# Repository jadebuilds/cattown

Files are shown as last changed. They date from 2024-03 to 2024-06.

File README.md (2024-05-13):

# cattown
Code for Cat Town Kickstarter project

# Poetry Environment Setup Instructions
-Make sure Python 3.12.3 exists on the system

-Install Poetry:

curl -sSL https://install.python-poetry.org/ | python3 -

May have to add this to path to run Poetry: `export PATH="/home/<YOUR USERNAME>/.local/bin:$PATH"`

The Poetry lock file and pyproject.toml should all be pulled from git.

You can now cd into `cattown/pi-controller` and run `poetry install` to make sure dependencies are installed.

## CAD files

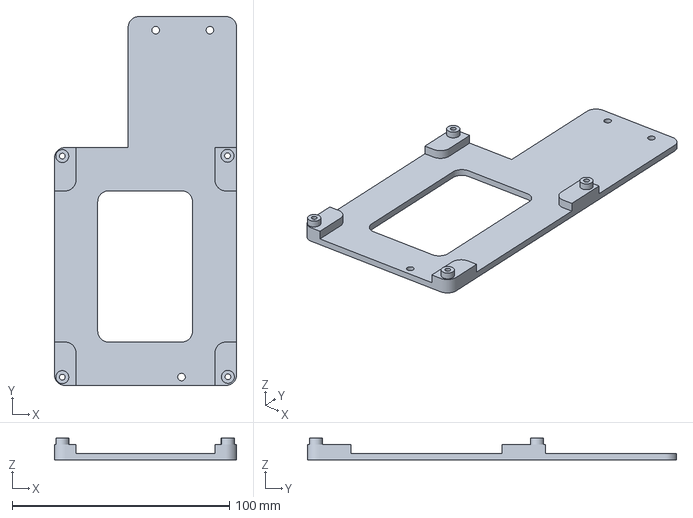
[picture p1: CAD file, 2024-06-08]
3d Print files/electronics/Powersupply main board mount.3MF
84.0 x 170.0 x 10.0 mm

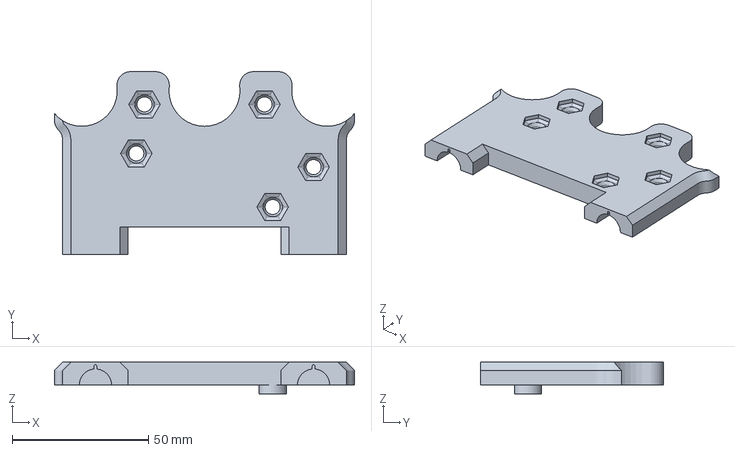
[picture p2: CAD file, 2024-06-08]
3d Print files/Gantry mount/top back gantry mount V0.02.3MF
110.0 x 67.0 x 11.6 mm

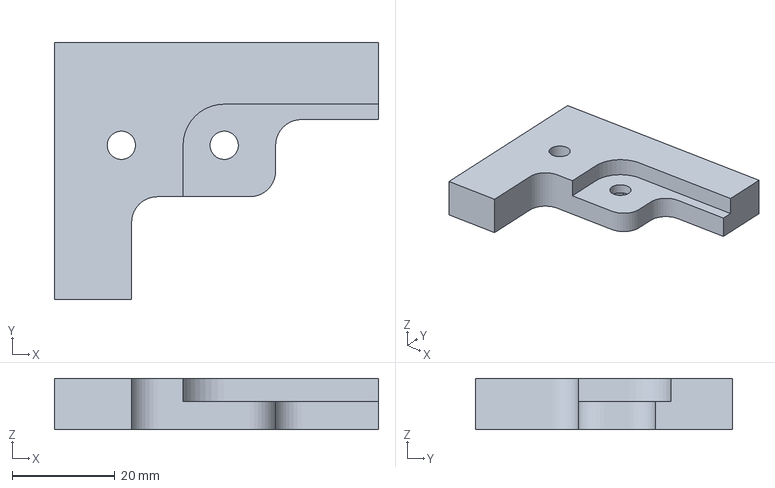
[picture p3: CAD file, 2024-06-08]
3d Print files/Idler mount/Top back idler mount.3MF
63.0 x 50.0 x 10.0 mm

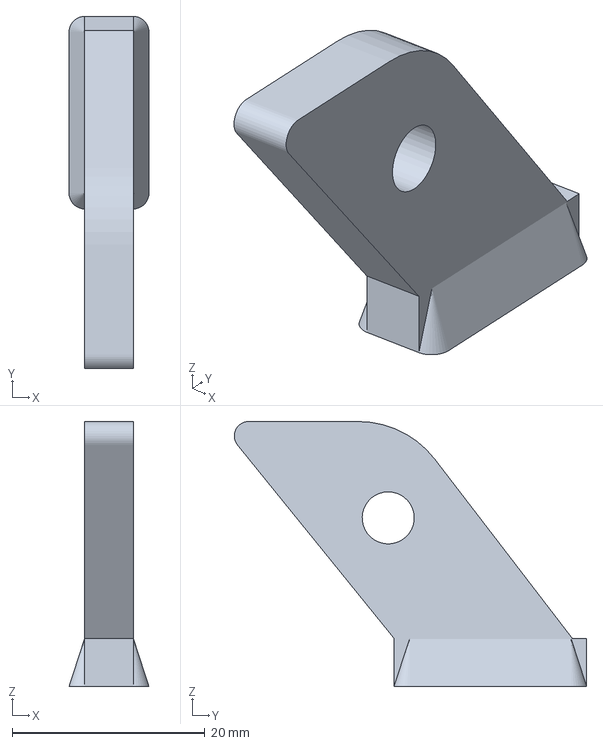
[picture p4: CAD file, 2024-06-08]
3d Print files/Jointer/v5_play_structure_v3_v25_joiner (1).3MF
8.30 x 36.6 x 27.5 mm

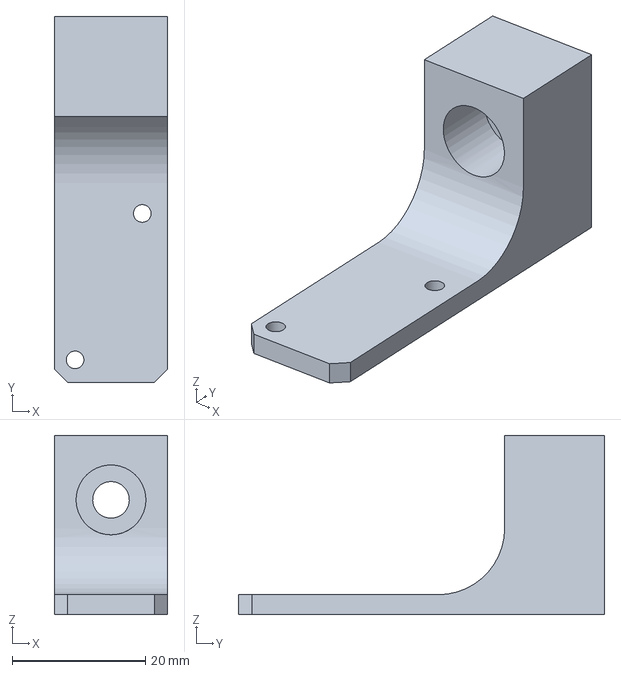
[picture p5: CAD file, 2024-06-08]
3d Print files/Limit switch mount/Limit switch mount v0.21.3MF
17.0 x 55.0 x 27.0 mm

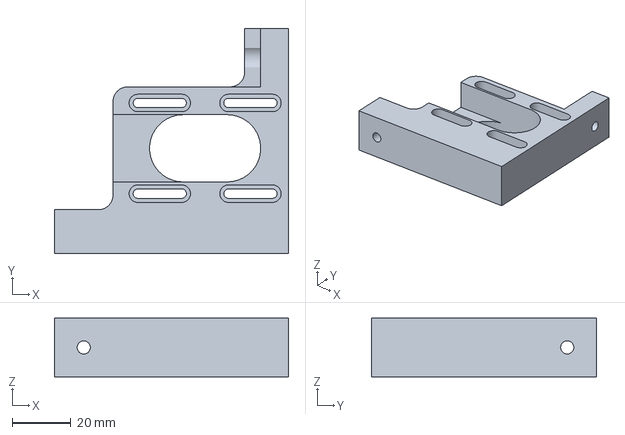
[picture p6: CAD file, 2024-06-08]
3d Print files/Motor mounts/Bottom motor mount.3MF
80.0 x 77.0 x 20.0 mm

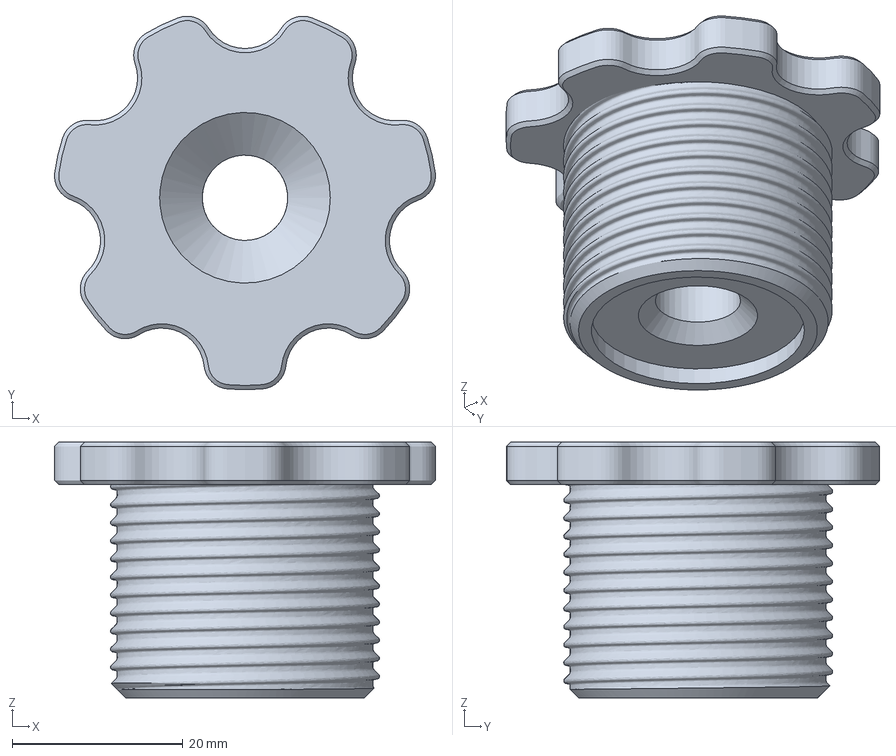
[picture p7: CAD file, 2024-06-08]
3d Print files/Tool head/Magnet holder.3MF
44.7 x 43.8 x 30.0 mm

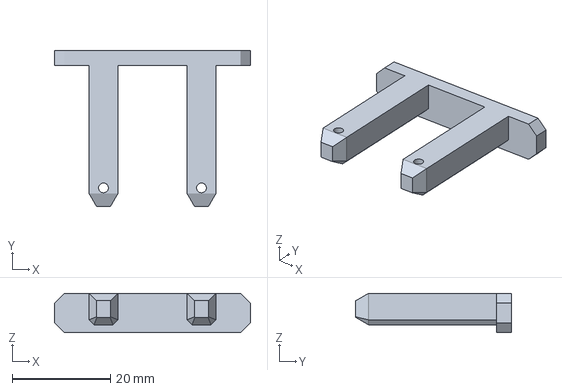
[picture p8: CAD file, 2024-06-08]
3d Print files/Tools/2040 frame mount hole guild.3MF
40.0 x 31.8 x 8.00 mm

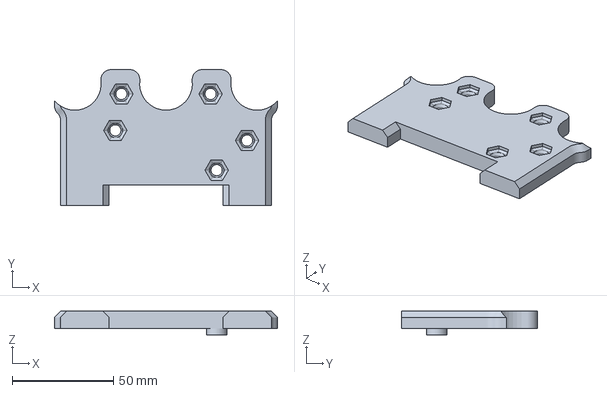
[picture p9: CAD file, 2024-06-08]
3d Print files/Gantry mount/top back gantry mount.3MF
110.0 x 67.0 x 11.6 mm

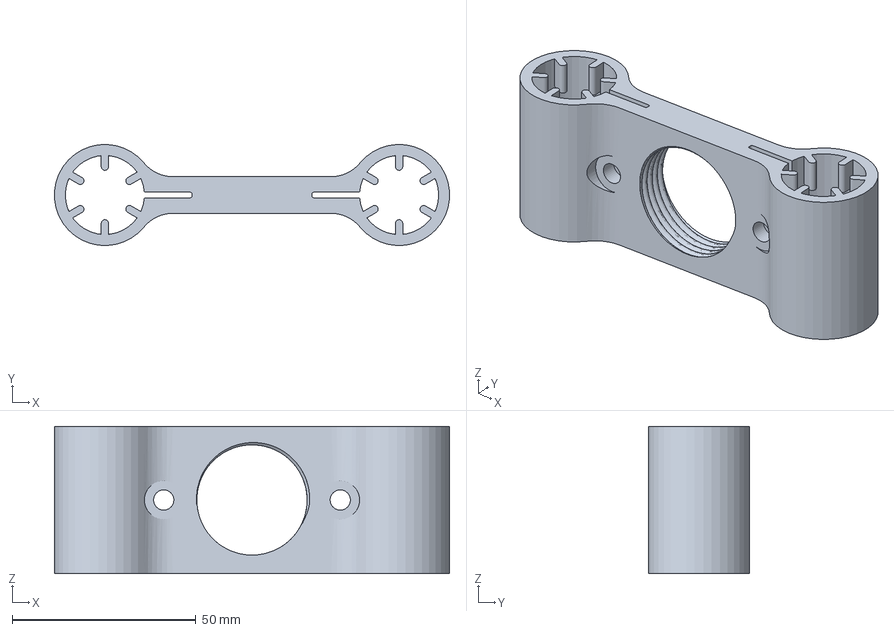
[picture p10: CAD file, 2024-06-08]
3d Print files/Tool head/Tool head.3MF
107.4 x 27.5 x 40.0 mm

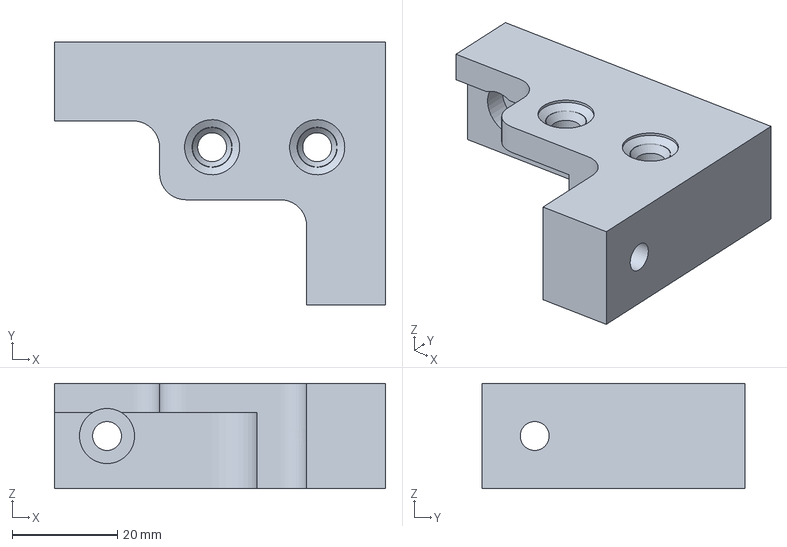
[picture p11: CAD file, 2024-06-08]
3d Print files/Idler mount/Bottom front idler mount.3MF
63.0 x 50.0 x 20.0 mm

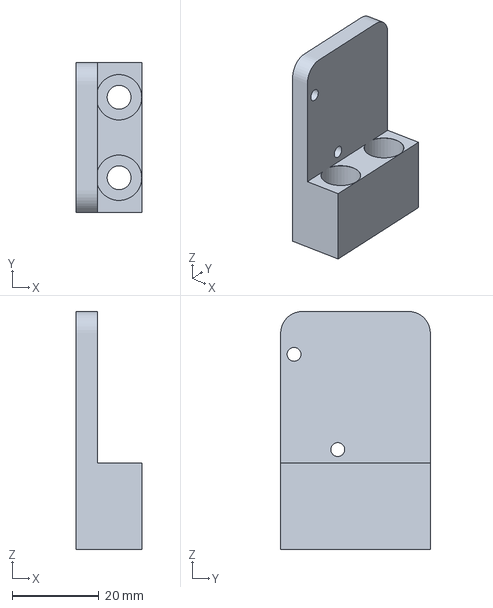
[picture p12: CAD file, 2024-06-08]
3d Print files/Limit switch mount/Limit switch mount.3MF
15.3 x 34.6 x 55.0 mm

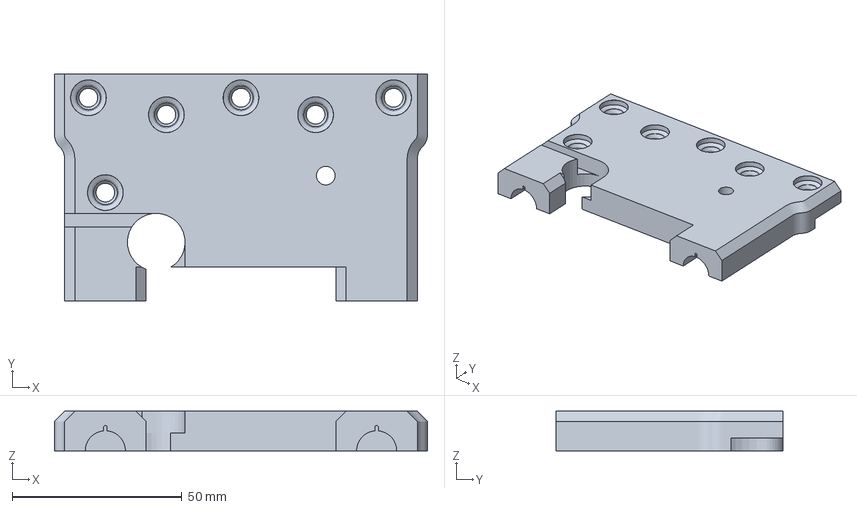
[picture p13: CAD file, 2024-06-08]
3d Print files/Gantry mount/top front gantry mount.3MF
110.0 x 67.0 x 11.7 mm

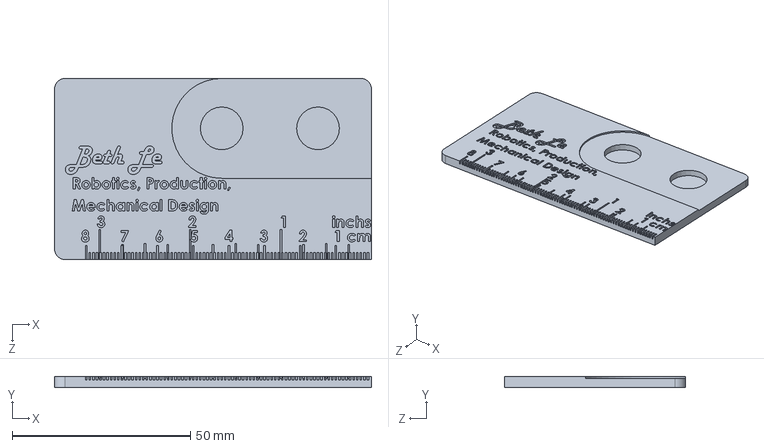
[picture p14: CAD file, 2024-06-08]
3d Print files/Tool head/Card.SLDPRT
88.9 x 3.00 x 50.8 mm

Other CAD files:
3d Print files/Idler mount/Bottom back idler mount.3MF
3d Print files/Motor mounts/Top motor mount.3MF
3d Print files/Gantry mount/Bottom back gantry mount.3MF
3d Print files/Idler mount/Top front idler mount v0.02.3MF
3d Print files/Gantry mount/Bottom front gantry mount.3MF
3d Print files/Gantry mount/top front gantry mount v0.02.3MF
3d Print files/Idler mount/Top front idler mount.3MF
3d Print files/Limit switch mount/Limit switch mount v0.20.3MF
3d Print files/Tool head/Belt holder v0.02.3MF
3d Print files/Tool head/Belt holder.3MF
3d Print files/Tool head/Bushing v0.02.3MF
3d Print files/Tool head/Bushing v0.03.3MF
3d Print files/Tool head/Bushing v0.04.3MF
3d Print files/Tool head/Bushing v0.05.3MF
3d Print files/Tool head/Bushing v0.06.3MF
3d Print files/Tool head/Bushing v0.07.3MF
3d Print files/Tool head/Bushing.3MF
3d Print files/Tool head/Magnet holder v0.02.3MF
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

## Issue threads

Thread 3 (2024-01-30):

Stabilizing strategy for the carriage

jadebuilds, 2024-01-30:
Decide on whether/how we're going to stabilize the carriage. Counterweights? Bungees? How will we access the lower corners of the platform? Or can we simply get away without it?

Requires some mechanical testing and prototyping.

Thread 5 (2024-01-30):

Jungle gym frontend

jadebuilds, 2024-01-30:
Design and lasercut some mouse houses, ramps/platforms, maybe some cat beds. Assemble onto the plywood sheet (presumably with wood glue?).

Decisions to make along the way:

* Size / orientation / number of mouse houses
* Freestanding or supported by the sheet?
* "What's fun for a cat?"
* Portrait/landscape orientation ("locks us in" -- although nb. we could make two gyms if we wanted to compare/contrast)

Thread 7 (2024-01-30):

Wire harnesses

jadebuilds, 2024-01-30:
Make a harness or harnesses to carry armature power to the motors.

The harness should ideally be connectorized to the electronics box such that the box can be detached for transport.

Leave conductors (or at least pins!) for 2x thermistors and 2x limit switches.

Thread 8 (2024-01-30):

Firmware: X/Y control

jadebuilds, 2024-01-30:
Write firmware to support play testing that:

* Includes some means of calibration -- probably as simple as a "disable motor drive" switch so we can manually spin the pulleys to a known starting position
* Allows X/Y control with the joystick
* Supports switching between direct motor drive (up/down = motor 1 extend/retract) and X/Y drive (up/down = up/down)

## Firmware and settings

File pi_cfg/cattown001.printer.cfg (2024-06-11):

# CAT TOWN V5
#
# This file is based off of the example Klipper config here:
# https://github.com/Klipper3d/klipper/blob/master/config/generic-bigtreetech-skr-v1.4.cfg
#
# Any line that isn't commented should be assumed to come from that.
#
# Pinout is here:
# https://raw.githubusercontent.com/bigtreetech/BIGTREETECH-SKR-V1.3/master/BTT%20SKR%20V1.4/Hardware/SKR-V1.4-Turbo-pinout.jpg
[mcu]
serial: /dev/serial/by-id/usb-Klipper_lpc1768_226002056324E6956623A363862100F5-if00

[include mainsail.cfg]  # this is just to make Mainsail happy. Does it matter for us?? idk

[duplicate_pin_override]
pins: P1.27

[printer]
kinematics: corexy
max_velocity: 10000
max_accel: 10000
max_z_velocity: 10
max_z_accel: 100

[stepper_x]
step_pin: P2.2
dir_pin: P2.6
enable_pin: !P2.1
microsteps: 16
rotation_distance: 60
# SKR1.4 uses the same P1.29/P1.28 pins for the X and Y endstops and Diag from the TMC2209s;
# I'm going to use the Z endstop pin for the actual endstop switch and leave the diag pins
# active for StallGuard detection. Hopefully that works! 
endstop_pin: !P1.27  # Z-stop pin (because X and Y-stop pins are overridden with diag) 
# endstop_pin:tmc2209_stepper_x:virtual_endstop
position_min:0
position_endstop:0
position_max: 1450  # approximately 57" X travel -- needs dialing in
homing_speed: 100
homing_retract_dist: 50

[stepper_y]
step_pin: P0.19
dir_pin: !P0.20
enable_pin: !P2.8
microsteps: 16
rotation_distance: 60
endstop_pin: !P1.27  # Beth's magical girl arc involves using the same endstop for both X and Y
# (which, as above, will actually be on this board's Z-stop connector)
# endstop_pin:tmc2209_stepper_y:virtual_endstop
position_min: 0
position_endstop: 0
position_max: 915  # leaving a few millimeters of tolerance at the upper end
homing_speed: 100

[stepper_z]
step_pin: P0.22
dir_pin: !P2.11
enable_pin: !P0.21
microsteps: 16
rotation_distance: 8
endstop_pin: !P1.27
position_endstop: 0.0
position_max: 300

[extruder]
step_pin: P2.13
dir_pin: !P0.11
enable_pin: !P2.12
microsteps: 16
rotation_distance: 33.500
nozzle_diameter: 0.400
filament_diameter: 1.750
heater_pin: P2.7
sensor_type: EPCOS 100K B57560G104F
sensor_pin: P0.24
control: pid
pid_Kp: 22.2
pid_Ki: 1.08
pid_Kd: 114
min_temp: -273.15
max_temp: 1000000

[fan]
pin: P2.3






########################################
# TMC2209 configuration
########################################

# see klipper3d.org/TMC_Drivers.html

[tmc2209 stepper_x]
uart_pin: P1.10
diag_pin: P1.29
run_current: 1.800
stealthchop_threshold: 0  # stealthChop all day (for quiet)
driver_SGTHRS: 255  # most sensitive (to try out)
diag_pin: ^P1.29
interpolate: True  # may reduce audible noise in exchange for minor positional inaccuracy
# Setting a hold current isn't recommended by the Klipper docs, but for our 
# application it makes a lot of sense: we do a lot of holding, we don't want to 
# run too hot, and also our carriage is super light and doesn't require much
# holding force. So I'm definitely trying this one out.
hold_current: 0.25

[tmc2209 stepper_y]
uart_pin: P1.9
diag_pin: P1.28
run_current: 1.8
stealthchop_threshold: 0
driver_SGTHRS: 255
diag_pin: ^P1.28
interpolate: True
hold_current: 0.25

#####################################################################
# 	Homing and Gantry Adjustment Routines
#####################################################################

[idle_timeout]
timeout: 1800


########################################
# G-code macros
########################################

[gcode_arcs]
resolution: 1.0

[homing_override]
gcode:
    #G91  # set to relative movement
    #G1 Y10  # move the carriage down by 10mm so that its homing tab is away from the limit switch
    #G92  # back to absolute
    G28 X0  # home on X axis first
    G1 X10  # move the gantry out to the right enough for the homing tab to contact the limit switch
    G28 Y0  # home on Y axis next (will bring the carriage up until it contacts the limit switch











########################################
# EXP1 / EXP2 (display) pins
########################################

# We don't need this right???? this is from the example .cfg

#[board_pins]
#aliases:
#    # EXP1 header
#    EXP1_1=P1.30, EXP1_3=P1.18, EXP1_5=P1.20, EXP1_7=P1.22, EXP1_9=<GND>,
#    EXP1_2=P0.28, EXP1_4=P1.19, EXP1_6=P1.21, EXP1_8=P1.23, EXP1_10=<5V>,
#    # EXP2 header
#    EXP2_1=P0.17, EXP2_3=P3.26, EXP2_5=P3.25, EXP2_7=P1.31, EXP2_9=<GND>,
#    EXP2_2=P0.15, EXP2_4=P0.16, EXP2_6=P0.18, EXP2_8=<RST>, EXP2_10=<NC>
#    # Pins EXP2_1, EXP2_6, EXP2_2 are also MISO, MOSI, SCK of bus "ssp0"

# See the sample-lcd.cfg file for definitions of common LCD displays.

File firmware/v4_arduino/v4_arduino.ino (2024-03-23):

#include <LiquidCrystal.h>
#include <TMCStepper.h>
#include "kinematics.h"
#include "pwm.h"
#include <arduino-timer.h>


/*
 * This is a first pass at making V4 work. I'm going just for "Manual Mode" right now;
 * accepting commands is for later.
 * 
 * I'm writing for E-S Motor 4260BL motors, assuming a Maslow-style design with a cable
 * pull doing stabilization.
 * 
 */

// ~~~~~~~~~~~~~~~~~~~~~~~~~~~~~~~~ CONSTANTS ~~~~~~~~~~~~~~~~~~~~~~~~~~~~~~~~

// todo should these be #defines?
const int DEBUG_UART_BAUD = 115200;

// I'm going fairly slowly for the moment because I expect to introduce discontinuities
// into the PWM output each time we change the PWM duty cycle (I keep disabling and re-enabling
// those channels)
const int MAIN_LOOP_PERIOD_MILLIS = 100;  // used in a delay() call in each loop()

const int PULLEY_DIAMETER_UM = 20000;  // 20 mm diameter pulley
const int PULLEY_PERIMETER_UM = 62832;  // 20 mm * pi

// How fast should a mouse accelerate? For my first pass I'll try 1G (9/8 m/s^2).
// With a 25 mm pulley diameter that works out to 
// dw/dt = a/r = (9.8 m/s^2) / (0.0125 m) * (60 s / 1 min) * (1 rev / 2π) = 7480 rpm/s
// So basically I'll allow the motor to ramp up to full over one second.
// Actually thinking about it I'm gonna use the Nice Round Number of 8000 rpm/s,
// which should work out to 1.07 G (very close) and invites a world of pleasant integral
// calculations. Also constitutes the motor spinning up fully over half a second which is
// nicne and round to think about.

// Note that I might move away from RPM as a measure of rotational speed but for now
// it seems both nicely legible and large enough to be pleasantly integral. So we're gonna
// stick with it for the moment and see how it feels.
//const int MAX_ACCEL_RPM_PER_S = 8000;

// Actually I want to accelerate much slower than that for testing. Let's do this (todo remove me)
const int MAX_ACCEL_RPM_PER_S = 200;

// In testing I'm finding that I can't get my steppers to spin faster than this without 
// starting to buzz and skip steps. Some work to do here around tuning SpreadCycle chopping
// to try to get it to run faster (or possibly checking out some of the other TMC chips, 2130
// I think?, that have a dedicated high-speed mode??)
const int MAX_RPM = 300;
const int MAX_NEG_RPM = -300;

// Leaving at the default number of microsteps for the moment.
const int MICROSTEPS = 8;

// For 8 microsteps and a 20 mm pulley diameter, this is equal to about 39.27 um. That's too low
// and introduces some rounding error. However when the pulley gets bigger it should be just fine
const int STRING_UM_PER_PULSE = PULLEY_PERIMETER_UM / (MICROSTEPS * 200);

// TMC2209 sense resistor, corresponding to the board it's on. Presumably in ohms?
#define R_SENSE 0.11f // todo this is for SilentStepStick; assuming BigTreeTech has cloned this value?? but plz confirm

// ~~~~~~~~~~~~~~~~~~~~~~~~~~~~~~~~ PIN ASSIGNMENTS ~~~~~~~~~~~~~~~~~~~~~~~~~~~~~~~~

// ~~~~~~~~~~~~~~~~ Front panel ~~~~~~~~~~~~~~~~

// Joystick
const int PIN_JOYSTICK_DOWN = 53;
const int PIN_JOYSTICK_UP = 51;
const int PIN_JOYSTICK_LEFT = 49; // TODO is this actually how this works?
const int PIN_JOYSTICK_RIGHT = 47;

// Buttons
const int PIN_MOUSE_BTN = 8;  // re-routed out of the 53-23 pin block so I could use pin 41 for PWM
const int PIN_DODGE_BTN = 9;  // re-routed out of the 53-23 pin block so I could use pin 39 for PWM

// Switches
const int PIN_MANUAL_MODE_SW = 37;
const int PIN_DIRECT_MODE_SW = 35;

// LCD screen
// https://learn.adafruit.com/character-lcds/wiring-a-character-lcd
const int PIN_LCD_RS = 33;  // pin 4 on the LCD screen (1/24/24 first bringup: green)
const int PIN_LCD_EN = 31;  // pin 6 on the LCD screen (1/24/24 first bringup: blue)
const int PIN_LCD_D4 = 29;  // pin 11 on the LCD screen (1/24/24 first bringup: purple)
const int PIN_LCD_D6 = 25;  // pin 13 on the LCD screen (1/24/24 first bringup: white)
const int PIN_LCD_D5 = 27;  // pin 12 on the LCD screen (1/24/24 first bringup: gray)
const int PIN_LCD_D7 = 23;  // pin 14 on the LCD screen (1/24/24 first bringup: purple)

LiquidCrystal lcd(PIN_LCD_RS, PIN_LCD_EN, PIN_LCD_D4, PIN_LCD_D5, PIN_LCD_D6, PIN_LCD_D7);

// ~~~~~~~~~~~~~~~~ Motors ~~~~~~~~~~~~~~~~


struct MotorPins {
  PwmChannel pwmChannel;
  int pinStep;
  int pinEn;
  int pinDir;
  int pinStepFeedback;  // Second GPIO tied to the STEP line so that we can pulse-count the PWM peripheral
  int driverAddress;
  HardwareSerial & uart;
};

const MotorPins motorPins[2] = {
  // Motor 0
  {
    PWMH3,  // pin 41 is PC9 / PWMH3 (from the datasheet) (Jade's notes: "RM-ESMO-01E Bringup")
    41, // note that this isn't really used, we go through the PWM peripheral above
    2,  // enable
    4,  // direction
    3,  // step feedback
    0,  // both pins left low
    Serial3  // Using RX3/TX3 on pins 14/15
  },
  // Motor 1
  {
    PWMH2,  // pin 39 is PC7 / PWMH2 (from the datasheet)  (Jade's notes: "RM-ESMO-01E Bringup")
    39, // note that this isn't really used, we go through the PWM peripheral above
    5, // enable
    7, // direction
    6, // step feedback
    0,  // both pins left low also -- at one point I had this on address "1" of the same UART bus,
        // but I've recently rewired the board to put them on separate UART buses at address 0
    Serial2  // Using RX2/TX2 on pins 16/17 (split out for convenience)
  }
};




// **** 3/10/24: Switching back to stepper motors, redoing motor pin declarations
// **** (keeping this here in case I change my mind again again)

// struct MotorPins {
//   int speedControlPin;
//   int encoderFeedbackPin;
//   int directionPin;
//   PwmChannel pwmChannel;
// };

// // I was following a color scheme on the board which doesn't match the motor's color
// // scheme. We did the harness following the motor. Sooooo there's a color change at
// // the interface to the board. Sorry about that. I probably... could have... IDK,
// // done that in a less confusing way.
// const MotorPins motorPins[2] = {
//   { // Motor 0
//     41,  // speed (*special PWM-capable pin!*) (yellow on board, blue on harness)
//     12,  // encoder (*special PWM-capable pin!*) (brown on board, yellow on harness)
//     10,  // direction (blue on board, white on harness)
//     PWMH3,  // Motor 0 is wired to pin 41 on the Arduino, which maps to PC9 on the MCU / channel PWMH3
//   },
//   { // Motor 1
//     39,  // speed (special PWM-capable pin!) (yellow on board, blue on harness)
//     13,  // encoder (special PWM-capable pin!) (brown on board, yellow on harness)
//     11,  // direction (blue on board, white on harness)
//     PWMH2,  // Motor 1 is wired to pin 39 on the Arduino, which maps to PC7 on the MCU / channel PWMH2
//     }
// };


// ~~~~~~~~~~~~~~~~~~~~~~~~~~~~~~~~ GLOBAL PROGRAM STATE ~~~~~~~~~~~~~~~~~~~~~~~~~~~~~~~~

bool modeManual = true;  // There is no alternative!! for the moment
bool modeDirect;  // Will get filled in setup()

// 10 concurrent tasks, millisecond resolution
//https://github.com/contrem/arduino-timer
Timer<10, millis> timer;


enum RotationalDirection { CW, CCW };

struct MotorState {
  TMC2209Stepper & driver;
  int32_t targetRpm;
  // I'm sticking to integer math for the moment since I don't know fixed point (yet! eek) and 
  // the Due doesn't have an FPU so floating point math is slow as shit. The "string length change per pulse" 
  // calculation is always going to be approximate / non-integral because it involves pi; so to avoid drift
  // I'm going to track motor state as encoder pulse count (definitely integral, 12/rotation) and redo the string
  // length calculation each time I need it (to avoid accumulating error).
  // Note that pulse count is signed so that it can go negative to account for turning "the other direction".
  // 
  // Sign convention: ** positive is clockwise, negative is counterclockwise **
  int encoderPulseCount;
  // Similarly, calibration is done in terms of pulse count so I can do apples to apples. We'll figure
  // out how exactly to calibrate later...
  bool calibrated;
  int pulseCountZeroStringLength;
  RotationalDirection direction;  // actual direction set by control pin (should get synchronized with targetRpm)
  // TODO do I store measurements of actual inst speed?
};

// todo can I declare these in the struct below? are they even worth including in the struct? idk
TMC2209Stepper driver_0(&motorPins[0].uart, R_SENSE, motorPins[0].driverAddress);
TMC2209Stepper driver_1(&motorPins[1].uart, R_SENSE, motorPins[1].driverAddress);

// TODO implement calibration routine!!!!!
// For the moment I'm going to assume that we start with the carriage in the exact middle of the platform.
// This means we'll have to do it by hand -- power the thing off (or at least release motor control somehow)
// and spin the pulleys manually until the carriage is correctly positioned. (The stabilizer will probably
// fuck this up when added and we'll probably need to change the routine pretty quickly. Hopefully it gives
// us at least a known starting position, like pulls the carriage down to the bottom).
//
// So I'm just hard-coding the "zero string length" pulse count. Here's my math:
// String length: sqrt((4 feet / 2)^2 + (82" / 2)^2) = 47.5" = 1206.7 mm
// The stepper should give us 1600 pulses per rotation, and every rotation is currently
// Note that this does not account for a bunch of things, such as the width of the 2x4s and the offset of 
// the motors, and I'll need to do a more careful geometric accounting some time quite soon.
int HALF_STRING_LENGTH_UM = 4 * 12 * 25400;
MotorState motorState[2] = {
  {driver_0, 0, 0, true, -1 * 200 * MICROSTEPS * HALF_STRING_LENGTH_UM / PULLEY_PERIMETER_UM, CW},
  {driver_1, 0, 0, true, -1 * 200 * MICROSTEPS * HALF_STRING_LENGTH_UM / PULLEY_PERIMETER_UM, CW},
};

// Some local state declared statically
int stringLength_mm_q8 [2];  // in millimeters, Q24.8
int stringLength_um[2];  // in inches, converted for the LUT (TODO redo the LUT in metric?)
int stringLength_in[2];  // in inches, converted for the LUT (TODO redo the LUT in metric?)
int x_in;
int y_in;

struct {
  bool up;
  bool down;
  bool left;
  bool right;
} joystickState {false, false, false, false};



// ~~~~~~~~~~~~~~~~~~~~~~~~~~~~~~~~ TIMER FUNCTIONS ~~~~~~~~~~~~~~~~~~~~~~~~~~~~~~~~

// Declared above setup() because apparently in C++ functions have to be declared before they're used,
// top to bottom, even if they're used "later" in runtime by a function?? that's pretty surprising.

uint32_t temp_freq_readout[2] = { 0, 0 };

// Utility function to occasionally read out what's going on.
bool send_state_debug_message(void * /* unused */) { // n.b. function signature is set by the timer library
  char buffer[100]; // Ensure this buffer is large enough for the resulting string
  snprintf(buffer, sizeof(buffer), "Motor 0: %d RPM / %d Hz; Motor 1: %d RPM / %d Hz; L1: %d, L2: %d, x: %d, y: %d", motorState[0].targetRpm, temp_freq_readout[0], motorState[1].targetRpm, temp_freq_readout[1], stringLength_in[0], stringLength_in[1], x_in, y_in);
  Serial.println(buffer);
  snprintf(buffer, sizeof(buffer), "Target RPM: Motor 0: %d; Motor 1: %d", motorState[0].targetRpm, motorState[1].targetRpm);
  return true;
}


// ~~~~~~~~~~~~~~~~~~~~~~~~~~~~~~~~ UTILITY FUNCTIONS ~~~~~~~~~~~~~~~~~~~~~~~~~~~~~~~~

// Used to decrease speed at constant rate to zero... in direct mode, and maybe elsewhere.
// Should be added to the value of the thing you want to decrease:
// 
//     motorSpeed += decrease_to_zero(motorSpeed, acceleration_per_loop_time);
// 
// Note that I got this wrong first try but GPT got it right... sigh
int32_t decrease_to_zero(int32_t counter, uint32_t increment) {
  if (counter == 0) {
    return 0;
  }
  else if (counter > 0) {
    // If the counter is positive and greater than increment, decrease by increment.
    // Otherwise, just decrease it to zero.
    return (counter > increment) ? -static_cast<int32_t>(increment) : -counter;
  }
  else {
    // If the counter is negative and its absolute value is greater than increment,
    // increase by increment. Otherwise, just increase it to zero.
    return (abs(counter) > static_cast<int32_t>(increment)) ? increment : -counter;
  }
}

// ~~~~~~~~~~~~~~~~~~~~~~~~~~~~~~~~ SETUP ~~~~~~~~~~~~~~~~~~~~~~~~~~~~~~~~

void setup() {
  /* 
   * Sets up pins, configures interrupts, starts the LCD screen manager, and so on. 
   * Does not do any active motor control, including calibration; that'll happen in loop().
   */


  // ~~~~~~~~~~~~~~~~ Initialize console log ~~~~~~~~~~~~~~~~
  Serial.begin(DEBUG_UART_BAUD);
  Serial.println("Starting setup()");


  // ~~~~~~~~~~~~~~~~ TMC2209 stepper drivers ~~~~~~~~~~~~~~~~

  Serial.println("    ... initializing motor drivers");

  motorPins[0].uart.begin(19200);
  motorPins[1].uart.begin(19200);

  motorState[0].driver.begin();
  motorState[1].driver.begin();

  motorState[0].driver.microsteps(MICROSTEPS);
  motorState[1].driver.microsteps(MICROSTEPS);

  // ~~~~~~~~~~~~~~~~ LCD ~~~~~~~~~~~~~~~~


  Serial.println("    ... initializing LCD screen");

  lcd.begin(16, 2);

  // ~~~~~~~~~~~~~~~~ PINS ~~~~~~~~~~~~~~~~

  Serial.println("    ... configuring pins");

  // Input pins, each with their own interrupt, all pulled up to 3.3V and switched to ground
  pinMode(PIN_MANUAL_MODE_SW, INPUT_PULLUP);
  pinMode(PIN_DIRECT_MODE_SW, INPUT_PULLUP);
  pinMode(PIN_JOYSTICK_LEFT, INPUT_PULLUP);
  pinMode(PIN_JOYSTICK_RIGHT, INPUT_PULLUP);
  pinMode(PIN_JOYSTICK_UP, INPUT_PULLUP);
  pinMode(PIN_JOYSTICK_DOWN, INPUT_PULLUP);
  pinMode(PIN_MOUSE_BTN, INPUT_PULLUP);
  pinMode(PIN_DODGE_BTN, INPUT_PULLUP);
  pinMode(PIN_DIRECT_MODE_SW, INPUT_PULLUP);
  attachInterrupt(digitalPinToInterrupt(PIN_MANUAL_MODE_SW), manual_mode_sw_isr, CHANGE);
  attachInterrupt(digitalPinToInterrupt(PIN_DIRECT_MODE_SW), direct_mode_sw_isr, CHANGE);
  attachInterrupt(digitalPinToInterrupt(PIN_JOYSTICK_LEFT), joystick_left_isr, CHANGE);
  attachInterrupt(digitalPinToInterrupt(PIN_JOYSTICK_RIGHT), joystick_right_isr, CHANGE);
  attachInterrupt(digitalPinToInterrupt(PIN_JOYSTICK_UP), joystick_up_isr, CHANGE);
  attachInterrupt(digitalPinToInterrupt(PIN_JOYSTICK_DOWN), joystick_down_isr, CHANGE);
  attachInterrupt(digitalPinToInterrupt(PIN_MOUSE_BTN), mouse_btn_isr, CHANGE);
  attachInterrupt(digitalPinToInterrupt(PIN_DODGE_BTN), dodge_btn_isr, CHANGE);

  // Pin feedback pins: similar, but no pullup because we're counting the PWM GPIO to set level both ways
  // Also I'm triggering on rising edge so as to count each pulse only once
  pinMode(motorPins[0].pinStepFeedback, INPUT);
  pinMode(motorPins[1].pinStepFeedback, INPUT);
  attachInterrupt(digitalPinToInterrupt(motorPins[0].pinStepFeedback), motor0_encoder_isr, RISING);
  attachInterrupt(digitalPinToInterrupt(motorPins[1].pinStepFeedback), motor1_encoder_isr, RISING);

  pinMode(motorPins[0].pinEn, OUTPUT);
  pinMode(motorPins[1].pinEn, OUTPUT);
  pinMode(motorPins[0].pinDir, OUTPUT);
  pinMode(motorPins[1].pinDir, OUTPUT);
  // Note that pin mode for the PWM pins gets handled through setupPwm() -- don't need to pinMode them

  // ~~~~~~~~~~~~~~~~ PWM peripheral ~~~~~~~~~~~~~~~~

  Serial.println("    ... starting PWM peripheral");
  setupPwm(); // calls out to pwm.h to do register-level stuff

  // ~~~~~~~~~~~~~~~~ Initialize switch values ~~~~~~~~~~~~~~~~

  modeDirect = true;
  // modeDirect = (digitalRead(PIN_DIRECT_MODE_SW) == LOW);
  // TODO read in manual mode switch too (when this starts to matter)


// ~~~~~~~~~~~~~~~~ Start timers ~~~~~~~~~~~~~~~~

  timer.every(1000, send_state_debug_message);

  // ~~~~~~~~ Game time :) ~~~~~~~~
    Serial.println("    ... welcome message");
  lcd.print("Cat Town 0.0.2");
}


// ~~~~~~~~~~~~~~~~~~~~~~~~~~~~~~~~ MAIN LOOP WOO ~~~~~~~~~~~~~~~~~~~~~~~~~~~~~~~~

void loop() {
  /*
   * I thought for a little while that we would do motor pulse generation/counting in the main loop,
   * but it turned out to be more straightforward to do elsewhere (counting in interrupts, generation
   * in the PWM peripheral). So this becomes relatively simple:
   * 
   * - Adjust string lengths based on the change in encoder position since last loop
   * - Adjust motor speed targets based on target acceleration requests from the joystick, bounded by string length
   *     - If mode is direct: directly set motor speed
   *     - Else: Look up partials from in LUT, multiply them in. Also look up X and Y and do some bounding.
   *       Maybe reduce speed target to slow to a stop at the edge of the platform????
   */

  timer.tick();  // advance the timer

  // ~~~~~~~~~~~~~~~~ Interpret joystick ~~~~~~~~~~~~~~~~

  // Direct mode: left/right controls Motor 0, up/down controls Motor 1.
  // Left and up "feel" more like retracting to me, right and down "feel" more like extending,
  // so that's how I've programmed it. We can always futz with this later.

  uint32_t accel = (MAX_ACCEL_RPM_PER_S * MAIN_LOOP_PERIOD_MILLIS) / 1000;

  if (modeDirect) {
    if (joystickState.left) {
      motorState[0].targetRpm -= accel;  // mouse go fast :shrug:
    } else if (joystickState.right) {
      motorState[0].targetRpm += accel;
    } else {
      motorState[0].targetRpm += decrease_to_zero(motorState[0].targetRpm, accel);
    }

    if (joystickState.up) {
      motorState[1].targetRpm -= accel;
    } else if (joystickState.down) {
      motorState[1].targetRpm += accel;
    } else {
      motorState[1].targetRpm += decrease_to_zero(motorState[1].targetRpm, accel);
    }
  }

  // X/Y mode: left/right and up/down map to actual X/Y motion.
  // This gets a little more complicated: we need to reach into the auto-generated LUT in kinematics.cpp
  // and look up mappings. I'm going to start with looking up the nearest based on the integral string length
  // and then worry about interpolation later.

  // // TODO call out to a calibration routine as appropriate (probably a little FSM?)
  stringLength_um[0] = (motorState[0].encoderPulseCount - motorState[0].pulseCountZeroStringLength) * STRING_UM_PER_PULSE;
  stringLength_um[1] = (motorState[1].encoderPulseCount - motorState[1].pulseCountZeroStringLength) * STRING_UM_PER_PULSE;

  stringLength_in[0] = stringLength_um[0] / 25400;  // These are integers, so rounding down to the nearest inch
  stringLength_in[1] = stringLength_um[1] / 25400;

  LocalKinematics kinematics = lookupTable[stringLength_in[1]][stringLength_in[0]];

  x_in = (int) kinematics.x;
  y_in = (int) kinematics.y;

  if (modeManual) {

    // Manual mode: apply X/Y kinematics!

    // ****** TODO FINISH MEEEEEEE THANKS <3 ****** //

    // // TODO handle errors
    // // TODO debug
    
    

    // TODO rewrite the kinematics lib as integers

    // rpm for string 0 = kinematics.dl1_dx * target_x_speed + kinematics.dl1_dy * target_y_speed
    // rpm for string 1 = kinematics.dl2_dx * target_x_speed + kinematics.dl2_dy * target_y_speed

    // TODO look up in LUT
    // TODO resolve unit mismatch between LUT (inches, sigh) and string length calc in UM
  }

  // ~~~~~~~~~~~~~~~~ Apply speed and acceleration limits ~~~~~~~~~~~~~~~~

  // todo
  for (int i = 0; i < 2; i++) {
    if (motorState[i].targetRpm > MAX_RPM) {
      motorState[i].targetRpm = MAX_RPM;
      
      lcd.setCursor(0,0);
      lcd.print("Motor speed max ");
    } 
    else if (motorState[i].targetRpm < MAX_NEG_RPM) {
      motorState[i].targetRpm = MAX_NEG_RPM;

      lcd.setCursor(0,0);
      lcd.print("Motor speed min ");
    }
  }

  // ~~~~~~~~~~~~~~~~ Send to motor ~~~~~~~~~~~~~~~~

  for (int i = 0; i < 2; i++) {
    uint32_t freq; // todo this won't get heap allocated will it?

    if (motorState[i].targetRpm > 0) {
      digitalWrite(motorPins[i].pinDir, LOW); // todo figure out this mapping on hardware
      motorState[i].direction = CW;  // todo get this mapping right
      freq = (motorState[i].targetRpm * MICROSTEPS * 200) / 60;  // One revolution is 200 fullsteps, 1 Hz is 1/60 minutes
    } else {
      digitalWrite(motorPins[i].pinDir, HIGH); // todo figure out this mapping
      motorState[i].direction = CCW; // todo get mapping right (as above)
      // todo is there a better way to abs() a signed integer than * -1?
      freq = (-1 * motorState[i].targetRpm * MICROSTEPS * 200) / 60;
    }
    temp_freq_readout[i] = freq;
    setPwmFrequency(motorPins[i].pwmChannel, freq);
  }
  
  // ~~~~~~~~~~~~~~~~ Sleep til next time ~~~~~~~~~~~~~~~~

  delay(MAIN_LOOP_PERIOD_MILLIS);
}

// ~~~~~~~~~~~~~~~~~~~~~~~~~~~~~~~~ INTERRUPTS ~~~~~~~~~~~~~~~~~~~~~~~~~~~~~~~~

void motor0_encoder_isr() {
  if (motorState[0].direction == CW) {
    motorState[0].encoderPulseCount++;
  } else {
    motorState[0].encoderPulseCount--;
  }
}

void motor1_encoder_isr() {
  if (motorState[1].direction == CW) {
    motorState[1].encoderPulseCount++;
  } else {
    motorState[1].encoderPulseCount--;
  }
}

void joystick_down_isr() {
  joystickState.down = (digitalRead(PIN_JOYSTICK_DOWN) == LOW);
  // if (joystickState.down) {
  //   lcd.setCursor(0,0);
  //   lcd.print("Joystick down!  ");
  // }
}

void joystick_up_isr() {
  joystickState.up = (digitalRead(PIN_JOYSTICK_UP) == LOW);
  // if (joystickState.up) {
  //   lcd.setCursor(0,0);
  //   lcd.print("Joystick up!    ");
  // }
}

void joystick_left_isr() {
  joystickState.left = (digitalRead(PIN_JOYSTICK_LEFT) == LOW);
  // if (joystickState.left) {
  //   lcd.setCursor(0,0);
  //   lcd.print("Joystick left!  ");
  // }
}

void joystick_right_isr() {
  joystickState.right = (digitalRead(PIN_JOYSTICK_RIGHT) == LOW);
  // if (joystickState.right) {
  //   lcd.setCursor(0,0);
  //   lcd.print("Joystick right! ");
  //   Serial.println("Joystick right pressed");
  // } else {
  //   Serial.println("Joystick right released");
  // }
}
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

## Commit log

2023-12-08 First-pass trajectory-accepting gRPC schema for platform
    Draft a Protobuf schema for the platform to use in accepting trajectories
    from mouse personalities. Note that I imagine using some other transport
    (TBD) to carry Protobuf messages to the microcontroller -- no guarantees
    I'll use Protobuf wire format either -- but wrapping it in a gRPC endpoint
    on the Pi so that it does actually serve this RPC interface.
2024-01-29 First-pass kinematics
    Auto-generate a kinematics lookup table using Jupyter.
    Note that I've plotted the six variables in heatmaps and they
    all look pretty good -- at least in the DataFrames. I'm not exactly
    sure that I've got the mapping to C++ struct array correct and that
    I didn't, I dunno, invert an axis there?
    Now to try integrating it into an Arduino sketch. That's gonna be a
    whole thing :)
2024-02-07 Bring up circuit board inputs: LCD, buttons, joystick
    Add a new sketch that's the starting point for V4 firmware on Arduino
    Due. Add pin configuration, initialization, and input handling interrupts
    for each of the inputs.
    For the moment, just display the most recent button press / joystick direction /
    etc on the LCD. Next up is actual motor control! and then some modal behavior
    I guess.
2024-02-07 Get the 4260BL motor spinning; check in some other Arduino bringup code
    I'm working on spinning the E-S Motor 4260BL. The 4260bl_pwm_encoder script
    does a ramp of PWM and measures RPM in order to generate the linearity plot
    in the Google Drive folder. I'm also checking in a few other bits of code
    I've been using to bring up the Arduino, just in case they're useful.
2024-02-15 Move kinematics files back out of subfolder
    Arduino won't compile files in subfolders, apparently,
    and I'm not ready to move out of the Arduino compilation process
    and set up my own Makefile etc.; so I'm going along with them.
2024-02-21 Upload some additional Arduino PoC scripts
    A few Arduino sketches in which I attempt to
    drive various motors various ways.
2024-03-11 Update Arduino sketches to use two stepper motors
    Adjust the PWM TMC2209 demo to use two motors, so I can exercise
    both channels of PWM. Note that this only works on Arduino Due!
    Adjust the TMCStepper demo slightly -- this is still targeted at one
    motor but I've included the correct pinout for both motors in the
    prototype control box, and we'll just comment them out one at a time.
    [tmc2209_pwm.ino, tmc2209_uart_tmcstepper.ino]
2024-03-11 Control box "direct mode" with steppers
    Update the control box firmware to use stepper motors.
    It's working pretty good!
2024-03-17 Set microsteps on the driver
    Zoda and I were observing that the motors were spinning surprisingly
    slowly today; I'm confused about this because MS1/MS2 are low on both
    drivers and so they should be using the default 1/8 microstep setting
    already. So maybe the TMCStepper driver object is overwriting that
    when we call begin()? I'm not sure.
    Anyway, when we do explicitly set the microsteps to 1/8
    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
2024-03-23 Get string length tracking working, index into LUT
    The LUT is linking!!! Woo!!! File size is way up. All it took was
    actually accessing the LUT and using it for something (so that the
    compiler didn't optimize it out). This rocks.
    Also encoding appears to be working too :) I'm seeing the right
    number of pulse counts per revolution.
    Next up: actually use the partial derivatives to track motion.
    Note that I'm not sure this will give us the positional accuracy
    we need -- we'll want to interpolate on X and Y in order to get
    finer grain position so that we can properly orient to get into
    mouse houses.
    [v4_arduino.ino]
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2024-05-09 fix a couple typos in notebook
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2024-05-23 move old, moving-cat-only simpler algo to new file in case we need to run it for speed comparisons
2024-05-23 Start defining motion patterns
    Lay out some quick-and-dirty convenience methods for GCode construction,
    since I don't see any in the libraries I've been using (I should maybe
    check Klipper code? but idk sometimes it's easier to just write it yourself).
    Use those to start defining custom motion patterns, building up to
    RoundedLineSegmentPath as a squiggly series of line segments. My sense is
    that this is the simplest way to translate a path on the grid map into
    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
2024-05-24 switch Rpi command line script display back from xwindows friendly to command line friendly
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2024-05-30 Start writing a class to control the printer
    Adds a KlipperInterface class (gets renamed in a few commits)
    to start talking to Klipper over its Unix domain socket. Note that
    this doesn't necessarily gain us much speed over Moonraker -- maybe 0.1s?
    -- but I'll take whatever speed I can get.
2024-05-30 Get Klipper Unix domain socket working
    Add a test_socket.py script. Rename KlipperInterface to KlipperSocket
    to be more specific. Make an number of tweaks on both ends til it
    works and I'm able to move the printer around!
2024-05-30 Add a draft map
    Key:
    0 or empty: cell is passable
    1: cell is impassable to toy
    2: cell is impassable to carriage! do not traverse!
    3: Opening to mouse house, passable
    4: Storage point in mouse house, passable
    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
    [map.csv]
2024-05-30 Add a script for real-time map display (currently WIP)
    This script needs some serious work -- it's currently just spinning up
    a thread internally to advance mouse motion, really needs to get
    plumbed through to the printer.
2024-05-31 Add base class (MotionDriver) and a mock for KlipperSocket (untested!!!!)
    I haven't gotten around to testing this yet! Might not work!! But,
    I did write the code and now I don't feel like using proper Git hygiene
    to stash it or whatever. It's All Burners Full Tilt right now, idk,
    fukkit. I'll get it working shortly anyway.
    Anyway the reason I'm pushing this is because I also wanted to increment
    command IDs to the printer so that I can properly track acks to
    requests.
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2024-06-02 Save cattown001's printer.cfg to the Git repo
    Save the Klipper config file so that we don't lose it :)
    [cattown001.printer.cfg]
2024-06-02 GET THAT V5 PROTOTYPE SQUIGGLIN'!
    Fix two little bugs in my squigglin code:
    - Use correct list indices for final segment
    - Fix sign error around I,J coordinates for left/right arcs
    The videos I'd sent out previously were working at the start
    because the Y-axis squiggles were correct (I think I'd gotten the
    signs entirely backward? or mostly backward? and fixed up/down
    but not left/right. This is what I get for switch/casing!)
    Then update the speed and MapConfig in test_socket.py to reflect
    settings for the actual platform.
2024-06-09 Update map.csv to 50 mm grid, Open Sauce configuration
    The last map.csv was a best-guess draft; now we've actually
    built the play structure for Open Sauce.
    Also I'm down-rezzing to a 50 mm grid, which I think will
    make navigation easier, give a little more room for error (not
    try to steer the mouse close to obstacles) and gives us a nice arc radius
    for squigglin' :)
    Note that for production we'll redesign the entire front panel
    and customize the map per unit. This is just hard coding for Open
    Sauce!!
    [map.csv]
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2024-06-09 fixes the mouse stall while the path is being replanned issue.
2024-06-10 Added poetry scrip to run the emulator, cleaned up map_display code with comments, removed some critical threading bugs from map_display, and added conditional path planning.
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2024-06-10 Minor tweak: Dodge bolts on lower right of mouse house
    The bolts for the lower right joiner are extending into the mouse
    house by just over half an inch, take off a little bit of motion
    from the right side of the "picking up the mouse" wiggle so
    that we don't crash into that bolt.
2024-06-10 Nail down the MapConfig for Open Sauce; allow negative offsets
    I'm doing a cheesy little thing where the 1th row is at -3.0 mm
    (actually, observing the actual geometry of the platform) but I
    wanna go to it anyway and just be 3 mm off, so I'm accepting negative
    coordinates and just rounding them off at 0.
    This will probably cause unexpected behavior at some point! I'm
    sorry in advance!
    [map.csv]
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2024-06-10 Add Point-to-Node conversion
    I'm going to stream live location from Moonraker in the hope of
    getting the same update rate that Mainsail features, which is pretty
    good. I think that just converting from the current reported location
    to the nearest tile and saying "I'm here now" is a good way of figuring
    out how far in the gcode queue we've gotten.
    Toward that end, add a to_node() function to custommap which converts
    back into map tile location (note that I'm starting to prefer the term
    "tile" since it implies area! ie it's more intuitive to say "where am
    I on the tile?" than it is to say "where am I in the node?").
    Include the map size in MapConfig so that I can error-check in the
    conversio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
2024-06-10 Add end_coordinates() to GCode objects
    I'm trying to figure out where the motion stage is on the move sequence
    it's been sent. I think the easiest way to do that is to take the current
    position reported by the toolhead and back out which tile we're on.
    We can then drop everything in the path that comes before that tile
    (assuming the path doesn't cross itself, which it shouldn't I think).
    Note that if the path crosses itself this will cause Weird Behavior!
    Anyway I'm adding a method to GCode objects that gives us where the
    GCode ends. I guess we could've inspected for an `x_mm` and `y_mm`
    attribute but that sounds ugly and like it doesn't age well...
2024-06-10 Midway cleanup
    This stuff really oughta be rearranged into other commits
    but it's midnight and I'm moving fast.
    * Fix some imports in commands.py
    * Update some references to gcodes (e.g. in mice.py)
    * Move out the MockMotionDriver from klipper.py
    * Pull out the monotonic ID from KlipperSocket to reuse in MoonrakerSocket
2024-06-10 Store latest location from Moonraker
    Now that we're subscribed to motion_output, crack the latest results
    into a Point and save it behind a Lock.
    This is gonna be a fairly reliable code path, I think, as it's used
    exactly as-is to power the Mainsail frontend.
    My notes on how I figured this out here:
    https://feline.atlassian.net/wiki/spaces/FES/pages/76578818/Getting+Real-Time+Status+from+Klipper
    I still need to figure out how to get this back to Zoda; I've added
    a to_node method but haven't yet figured out where the right place
    to invoke it is. That's a tomorrow problem I think~
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2024-06-10 Add Path object as interface between planning and machine
    Take a crack at adding a nice ergonomic interface between path
    planning and Klipper. This Path object is meant as a kind of drop-in
    replacement for the Paths we've been generating, but adds methods
    that hopefully let it be usefully shared and manipulated on both
    ends.
    The Klipper socket interface should call commit() when it submits
    movements to the socket and advance() when it receives feedback
    that the machine has advanced; the path planning should call
    clear() / truncate_at() when it wants to re-plan and extend()
    when it wants to add movement.
    Still to figure out:
    * How do we incorporate picking up and dropping off mice?
    * Genera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
2024-06-11 Update config file to run faster
    Beth does some magic to the config file and gets us to high speed.
    This fucking rocks. This is lit. This fucking rocks. Get stoked!!!
    Changes involved:
    - Increase TMC2209 run_current
    - Switch to spreadCycle
    [cattown001.printer.cfg]
2024-06-11 Add position subscription and PathFollower object
    Add a callback mechanism to MotionDriver and implement in MoonrakerSocket
    so that we can get live updates as callbacks. Note that we will have to be
    careful about threading with this callback system / not block in callbacks
    or else we'll slow down the websocket connection!
    Anyway, this lets me construct a PathFollower object which takes a
    MotionDriver and executes Path following on it quite simply. (I thought
    about making those utility functions on MotionDriver, but IDK, I figured
    keeping MotionDriver as an abstract interface was cleaner...)
    Subscription is currently not implemented on MockMotionDriver (I will do
    this shortly / in an upcomi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
2024-06-11 Finish PathFollower by actually submitting motion; allow restart
    This is turning into a cute little multi-threading project, with two
    major threads interacting back and forth through the Path and
    PathFollower object, namely the Klipper websocket receive thread
    bringing in position updates and the path planning thread redoing
    the upcoming path based on camera updates.
    Add a MotionStyle ABC that allows swappable motion styles for going
    from one tile to another. This actually has a serious design flaw
    right now which is that it doesn't allow lookahead; SimpleSquiggleArcPath
    does lookahead, which is really important and useful in order to
    corner quickly, and I think we'll want to continue doing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
2024-06-11 Slow down homing a bit
    Homing sequence was a bit too speedy, when it goes wrong it chatters
    in a way that startles me. Let's do a compromise medium pace :)
    [cattown001.printer.cfg]
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2024-06-11 Bugfixes in Path / PathFollower system
    Will probably collide with ToolheadTrajectory rename ugh
2024-06-11 Moonraker bugfixes: fix wait for new location, fix print statement
2024-06-12 Renamed two files, fixed small bugs, and currently WIP to make map_display work with ToolheadTrajectory and PathFollower
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2024-06-12 Bugfix: don't error when crossing off-path tiles
    Catch a mis-re-raised ValueError (re-raised as IndexError in advance()
    because that makes a lot more sense to me) that ToolheadTrajectory
    throws when a tile is not on the path. This was causing issues right
    at startup because the toolhead wasn't on the path yet. This should be
    fine -- we're using absolute-coordinate moves so the first motion
    segment will just cross any tiles it needs to to get to the start
    of the trajectory.
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2024-06-12 Downgrade map to 3 panels for pre-Open Sauce testing
    We weren't able to upgrade to four panels because the new belts haven't
    arrived yet. Hopefully showing up tomorrow???? or else we'll have
    a scramble to rebuild at Open Sauce for a three-panel design!
    Anyway I want to try out map_display with panel control!
    [map.csv]
2024-06-12 Add manual control app, get toolhead control working
    I was struggling with map_display, so I'm taking the liberty of
    forking it into a separate script that does point-and-click mouse
    control. Get the Toolhead actually working!
    I ran into some weird things on the way over from map_display...
    I think the y/x flipping we were doing is not actually correct. I'm
    kinda not sure why it's working as is. I've undone them in manual_control.
    Currently I'm having issues with go_to_coords where the path it
    generates goes through stuff. I think there's probably an offset somewhere,
    hm. Or flipping the map did something weird? IDK. It's a tomorrow problem!
2024-06-12 Add colored logging
    I have something going wrong with my toolhead pausing mechanism --
    when we change destination mid-flight it stops at the pivot point
    where the path changed. I dunno why this is yet, but what I do know
    is that better visibility is always the recipe!
    To this end, adopt the package `colorlog` to make our log records
    prettier and specifically so that I can have certain log records
    stand out from the spool; and convert the print statements we still
    have sitting around to log records so they get colored too.
2024-06-12 Fix re-routing in flight (and some debug logs)
    I'd broken Zoda's go_to_coords() debugging in converting from print
    statements, my bad! fix that.
    Also rename "self.paused" on Toolhead to be more clear what it's
    actually doing. I really don't like that mechanism, would love to
    get rid of the statefulness there and in "self.on_path" also. Feels
    like workarounds. I'll see if I can simplify that going forward.
    Anyway, fix that logic too. Now we should be able to re-route in
    flight without issue.
    Another issue here was that go_to_coords() is (I think) including
    the starting tile in its returned path, which makes sense but was
    causing bugs when it was passed as-is to extend() and we ended up
    wit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
2024-06-14 Swap print statements in ccv.py with logging; few tweaks
    Chris has great commenting and debug messages, just phrased as prints.
    Convert those to log records with the appropriate log level so they'll
    come through nicely color-coded.
    Also make a few changes that the IDE recommends which I think might've
    fallen through the cracks when porting to a class -- variable `fdir` was
    not declared and I don't think we need it, and one other thing I forget.
2024-06-14 Change map to 4-panel Open Sauce layout
    We got the full four-panel system built today and it's a beaut!
    Get the map CSV in place so we can test it out tomorrow :)
    [map.csv]
2024-06-14 Add piecewise linear squiggles
    Use some fast-and-loose class derivation and some help from GPT
    to overload squiggle arcs into piecewise linear sections. These
    will probably also suffer from cornering velocity controls, but I
    think with 2 segments per arc it will maybe move quickly. IDK!
    We'll try it out on the wall and see what happens *shrug*
    Update: this is severely broken lol. It does produce a fascinatingly
    erratic geometric pattern, but it seems like it's off by as much as
    1 entire grid tile so I don't think it's usable. Oh well. Maybe
    we'll even troubleshoot it tomorrow huh
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2024-09-15 Minor bugfixes during bringup at Open Sauce
    Map config has changed during assembly (we will really need to figure
    this one out for production!)
    Also a few other tweaks
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2024-09-15 Changes... since Open Sauce?
    - Redo the map to expose the inside of mouse houses
    - Add infinite loop script
    - Basically disable the "on path" mechanism (wasn't working)
    - Bugfixes
    - Correct the X/Y configuration
    [map.csv]
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2024-11-04 With Chris: fix a few syntax errors, switch to live framebuffers
    Tweaks to ccv to get it running on the Pi again
    Also only use the new callback if it's passed (to avoid error
    "NoneType is not callable")
